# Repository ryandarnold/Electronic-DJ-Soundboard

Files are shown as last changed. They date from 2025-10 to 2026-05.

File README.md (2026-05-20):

# Electronic-DJ-Soundboard
The Electronic DJ Soundboard I designed in Eagle while serving as hardware lead on a 4-person team. I picked out the chips, designed the circuit, performed layout, soldered all components and tested and verified the board with a power supply and digital multimeter. 

I also coordinated with the embedded software lead on GPIO pin assignments, I/O functionality, communication protocol usage, and peripheral connections to support embedded firmware development.

<p align="center">
  
  <br>
  <em> The DJ circuit board outside its enclosure. I laser cut the enclosure and sanded it so it would fit together. </em>
</p>

<p align="center">
  
  <br>
  <em> The DJ circuit board from another angle. </em>
</p>

<p align="center">
  
  <br>
  <em> The main DJ circuit board.</em>
</p>

## Hardware: 

1. **TM4C123GH6PMI microcontroller launchpad** (as the main MCU for the project)
2. **Ceramic and Tantalum capacitors** (various purposes)
3. **ESP8266 Wifi module** (for saving user-made sound clips)
4. **TLV5618ACP DAC** (for outputting to the two speakers)
5. **MC34119 audio amplifier** (for amplifying the DAC output to the speakers)
6. **ULN2803a transistor array** (for powering the LED arrays)
7. **LM4041CILPR shunt voltage reference** (required for the TLV DAC)
8. **Resistors** (various purposes)
9. **Wire nuts** (for connecting the LEDs to the transistor array)
10. **LM2937 3.3 V regulator** (for powering different parts of the board)
11. **Testpoints** (for verifying that different parts of the board work)
12. **Blue, Red and Yellow LEDs** (to light the translucent buttons when pushed)
13. **MC7805ABTG 5V regulator** (for powering the LED array)
14. **8-ohm speakers** (for outputting user-made sounds)
15. **Audio jack** (so you can choose to use the built-in speakers or attach your own personal speaker for better sound quality)
16. **Pin headers**(to connect the launchpad to the board, and to have maximum flexibility in testing prototype)
17. **DC power connector** (to power the board)
18. **ST7735R LCD** (for displaying info to the user)
19. **Wood enclosure** (to store all electronics)
20. **Turn potentiometer** (for volume change)
21. **Slide potentiometer** (for tone change)

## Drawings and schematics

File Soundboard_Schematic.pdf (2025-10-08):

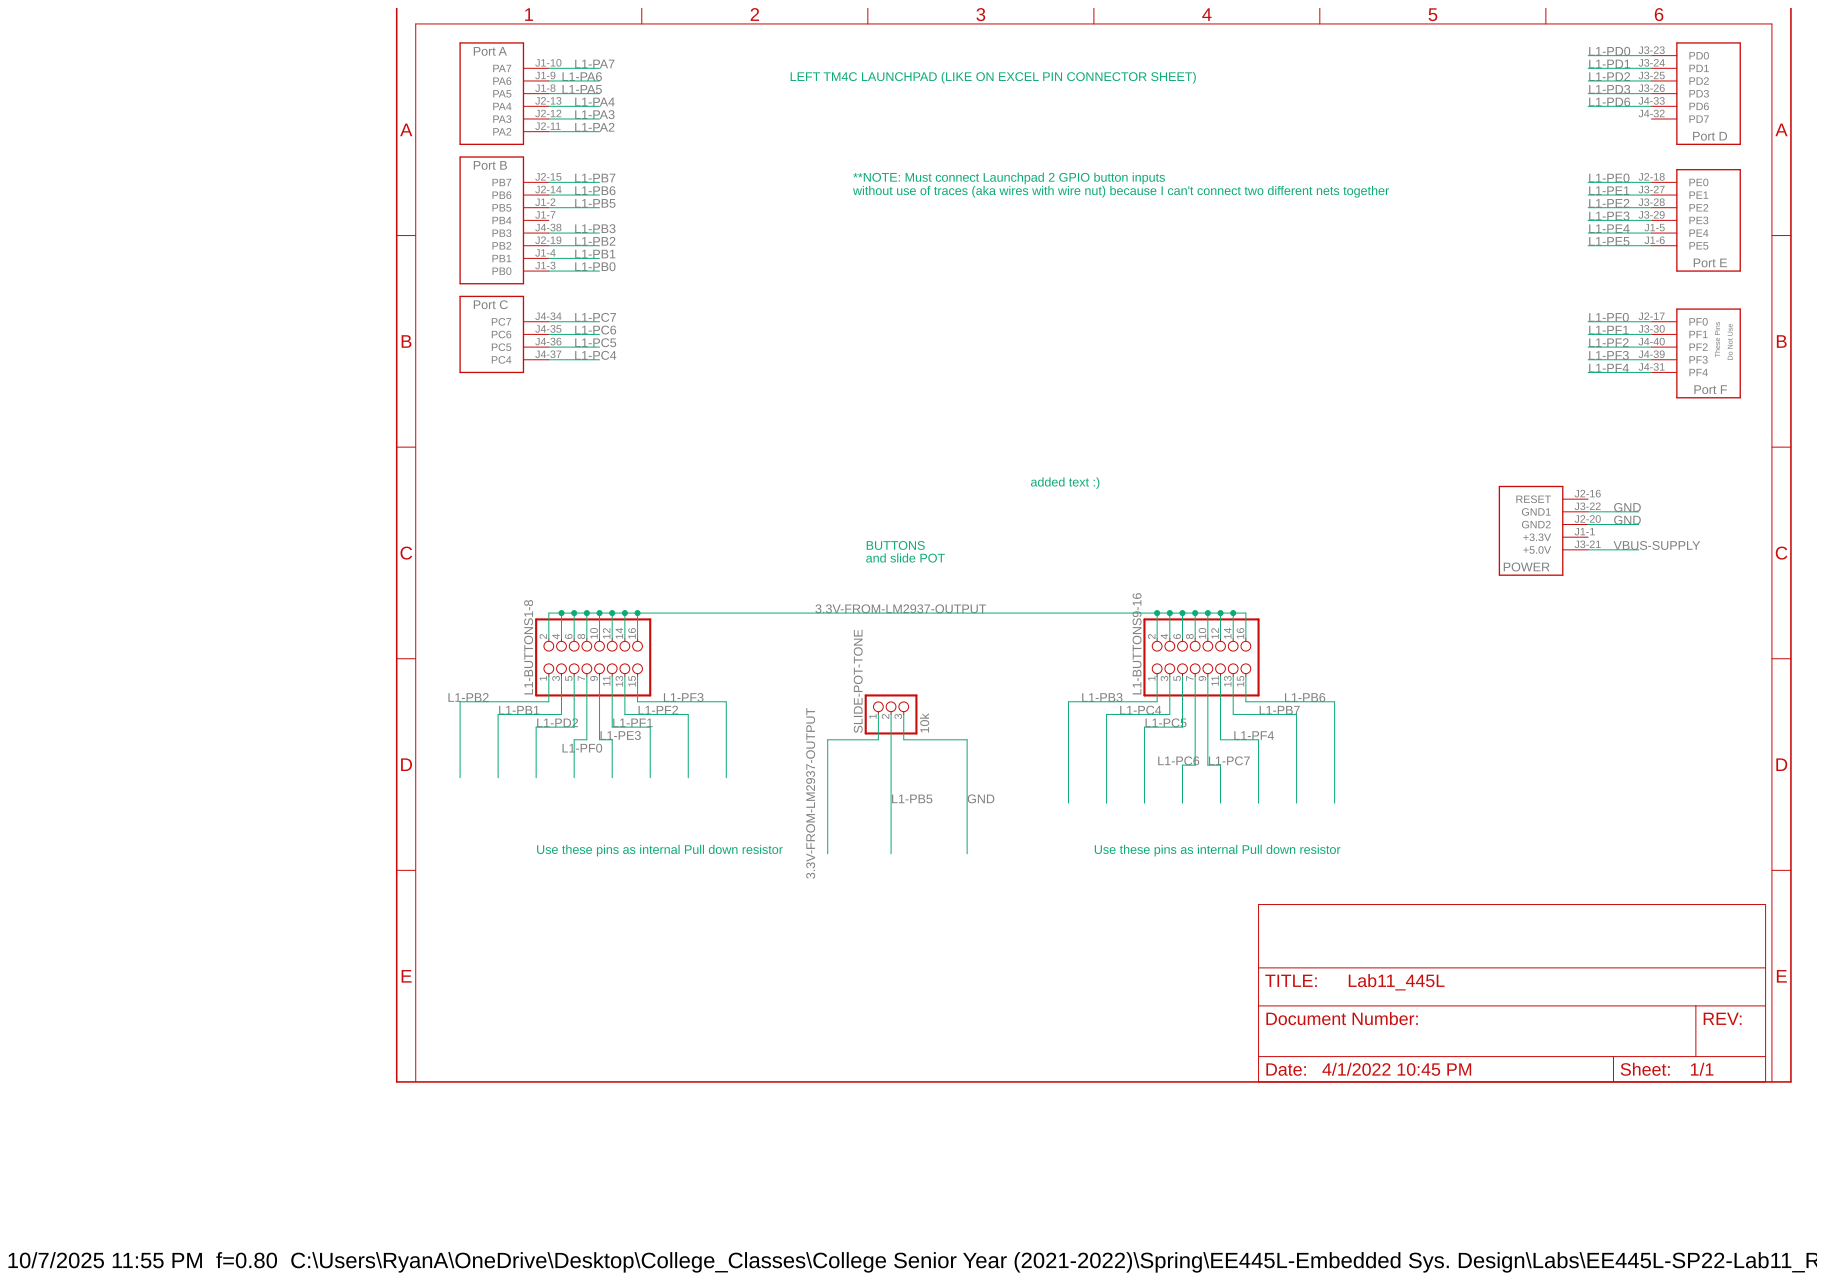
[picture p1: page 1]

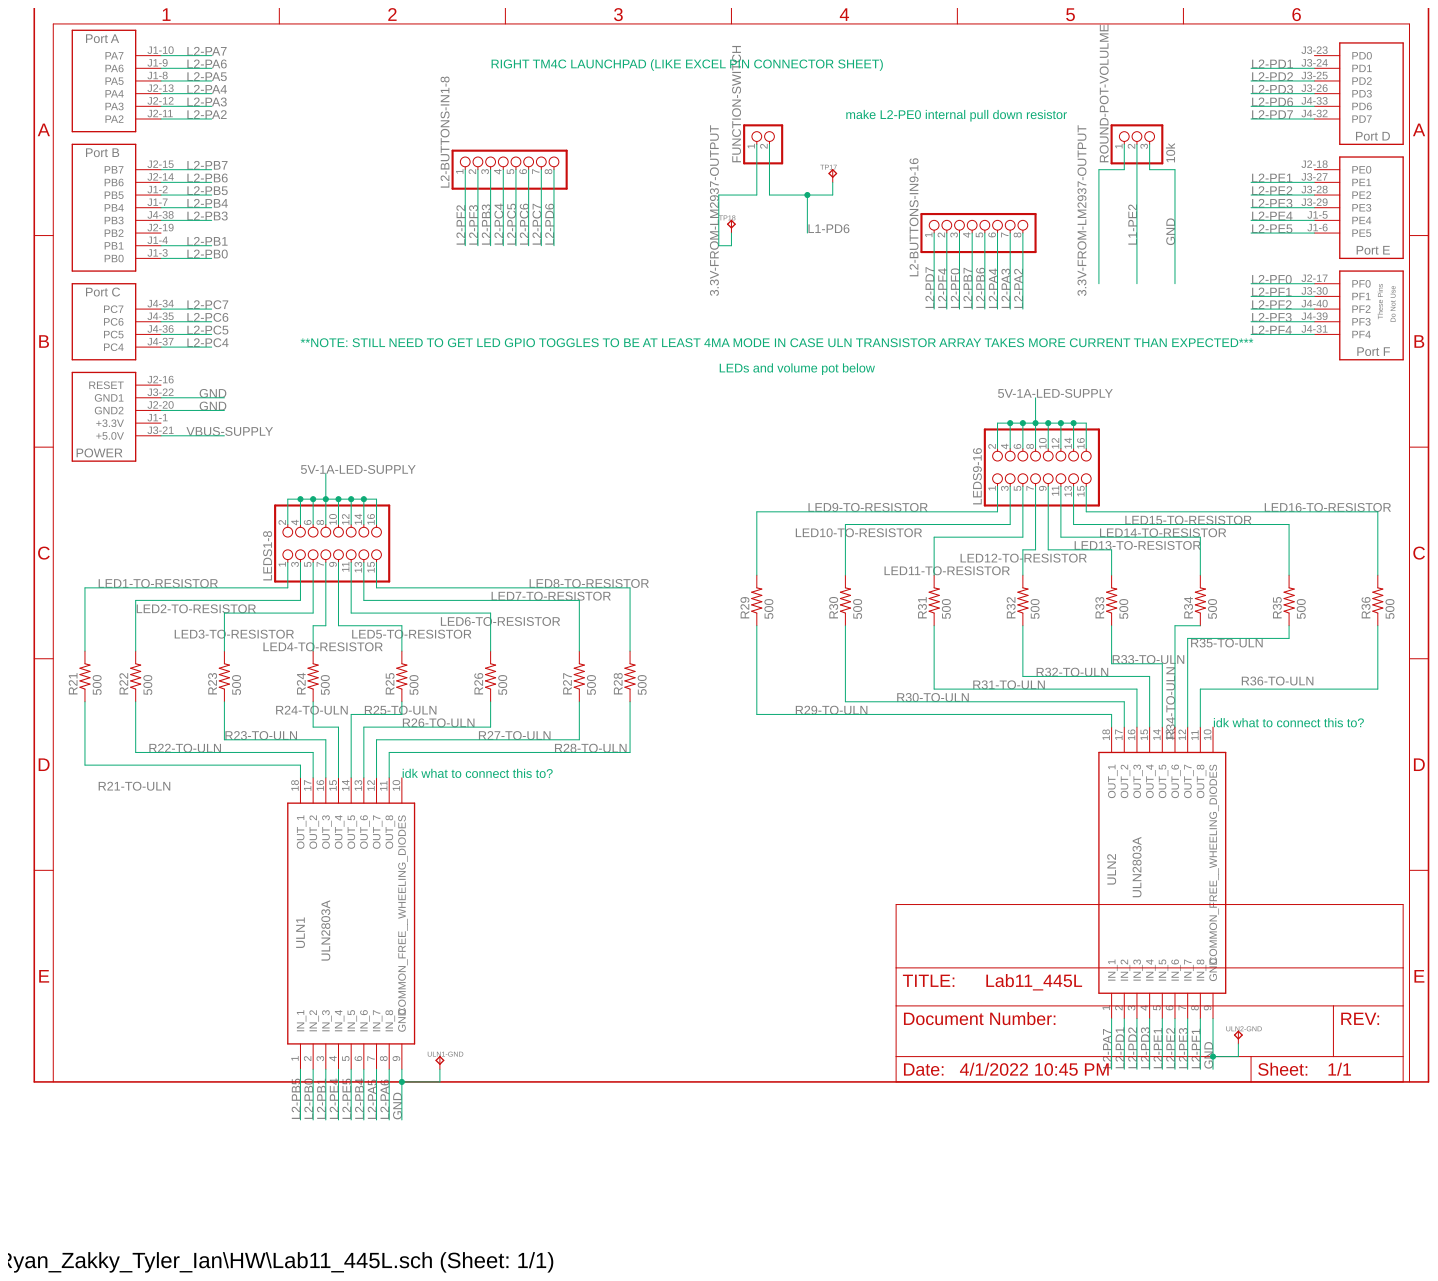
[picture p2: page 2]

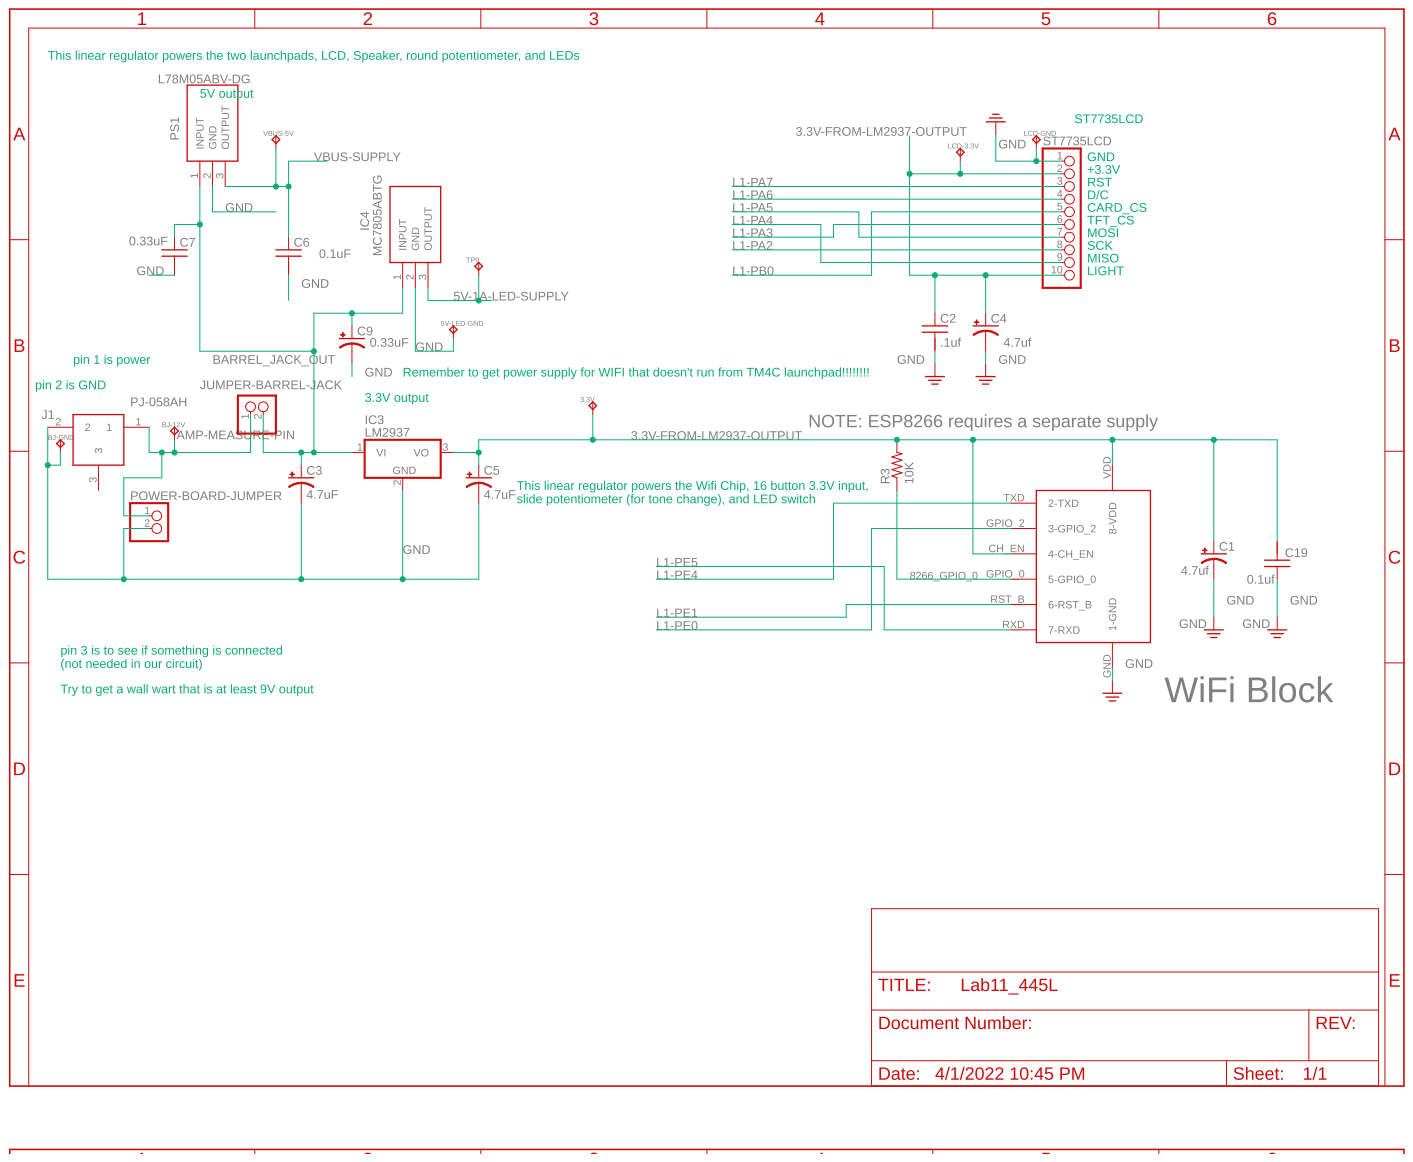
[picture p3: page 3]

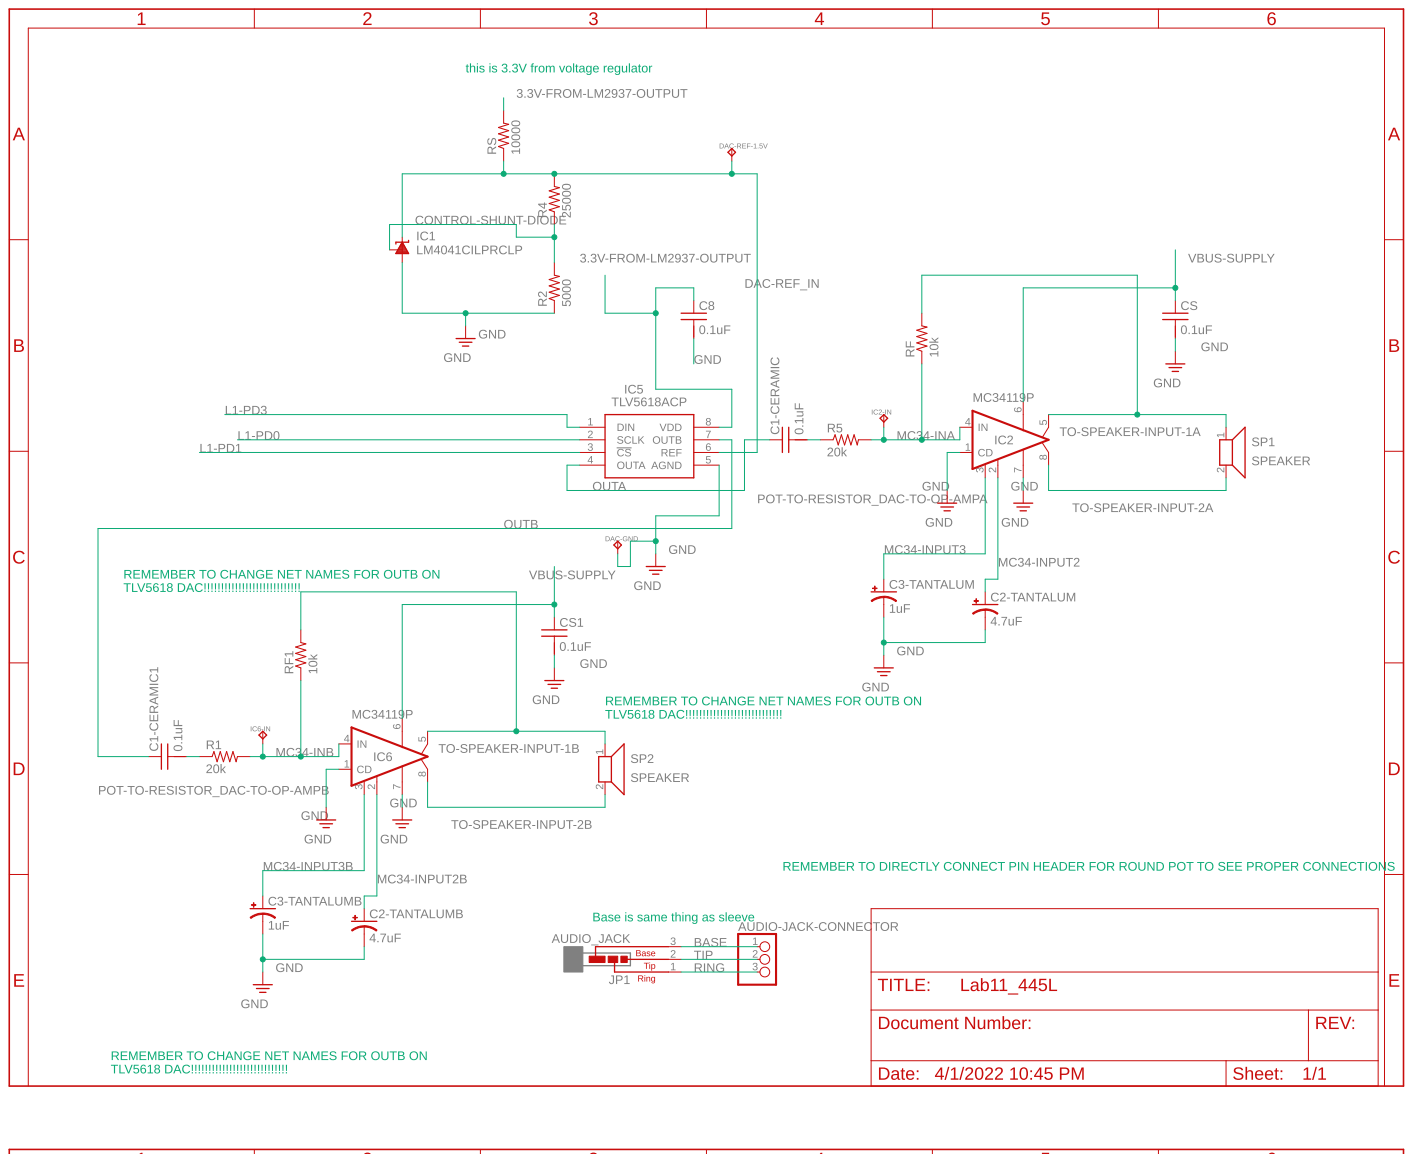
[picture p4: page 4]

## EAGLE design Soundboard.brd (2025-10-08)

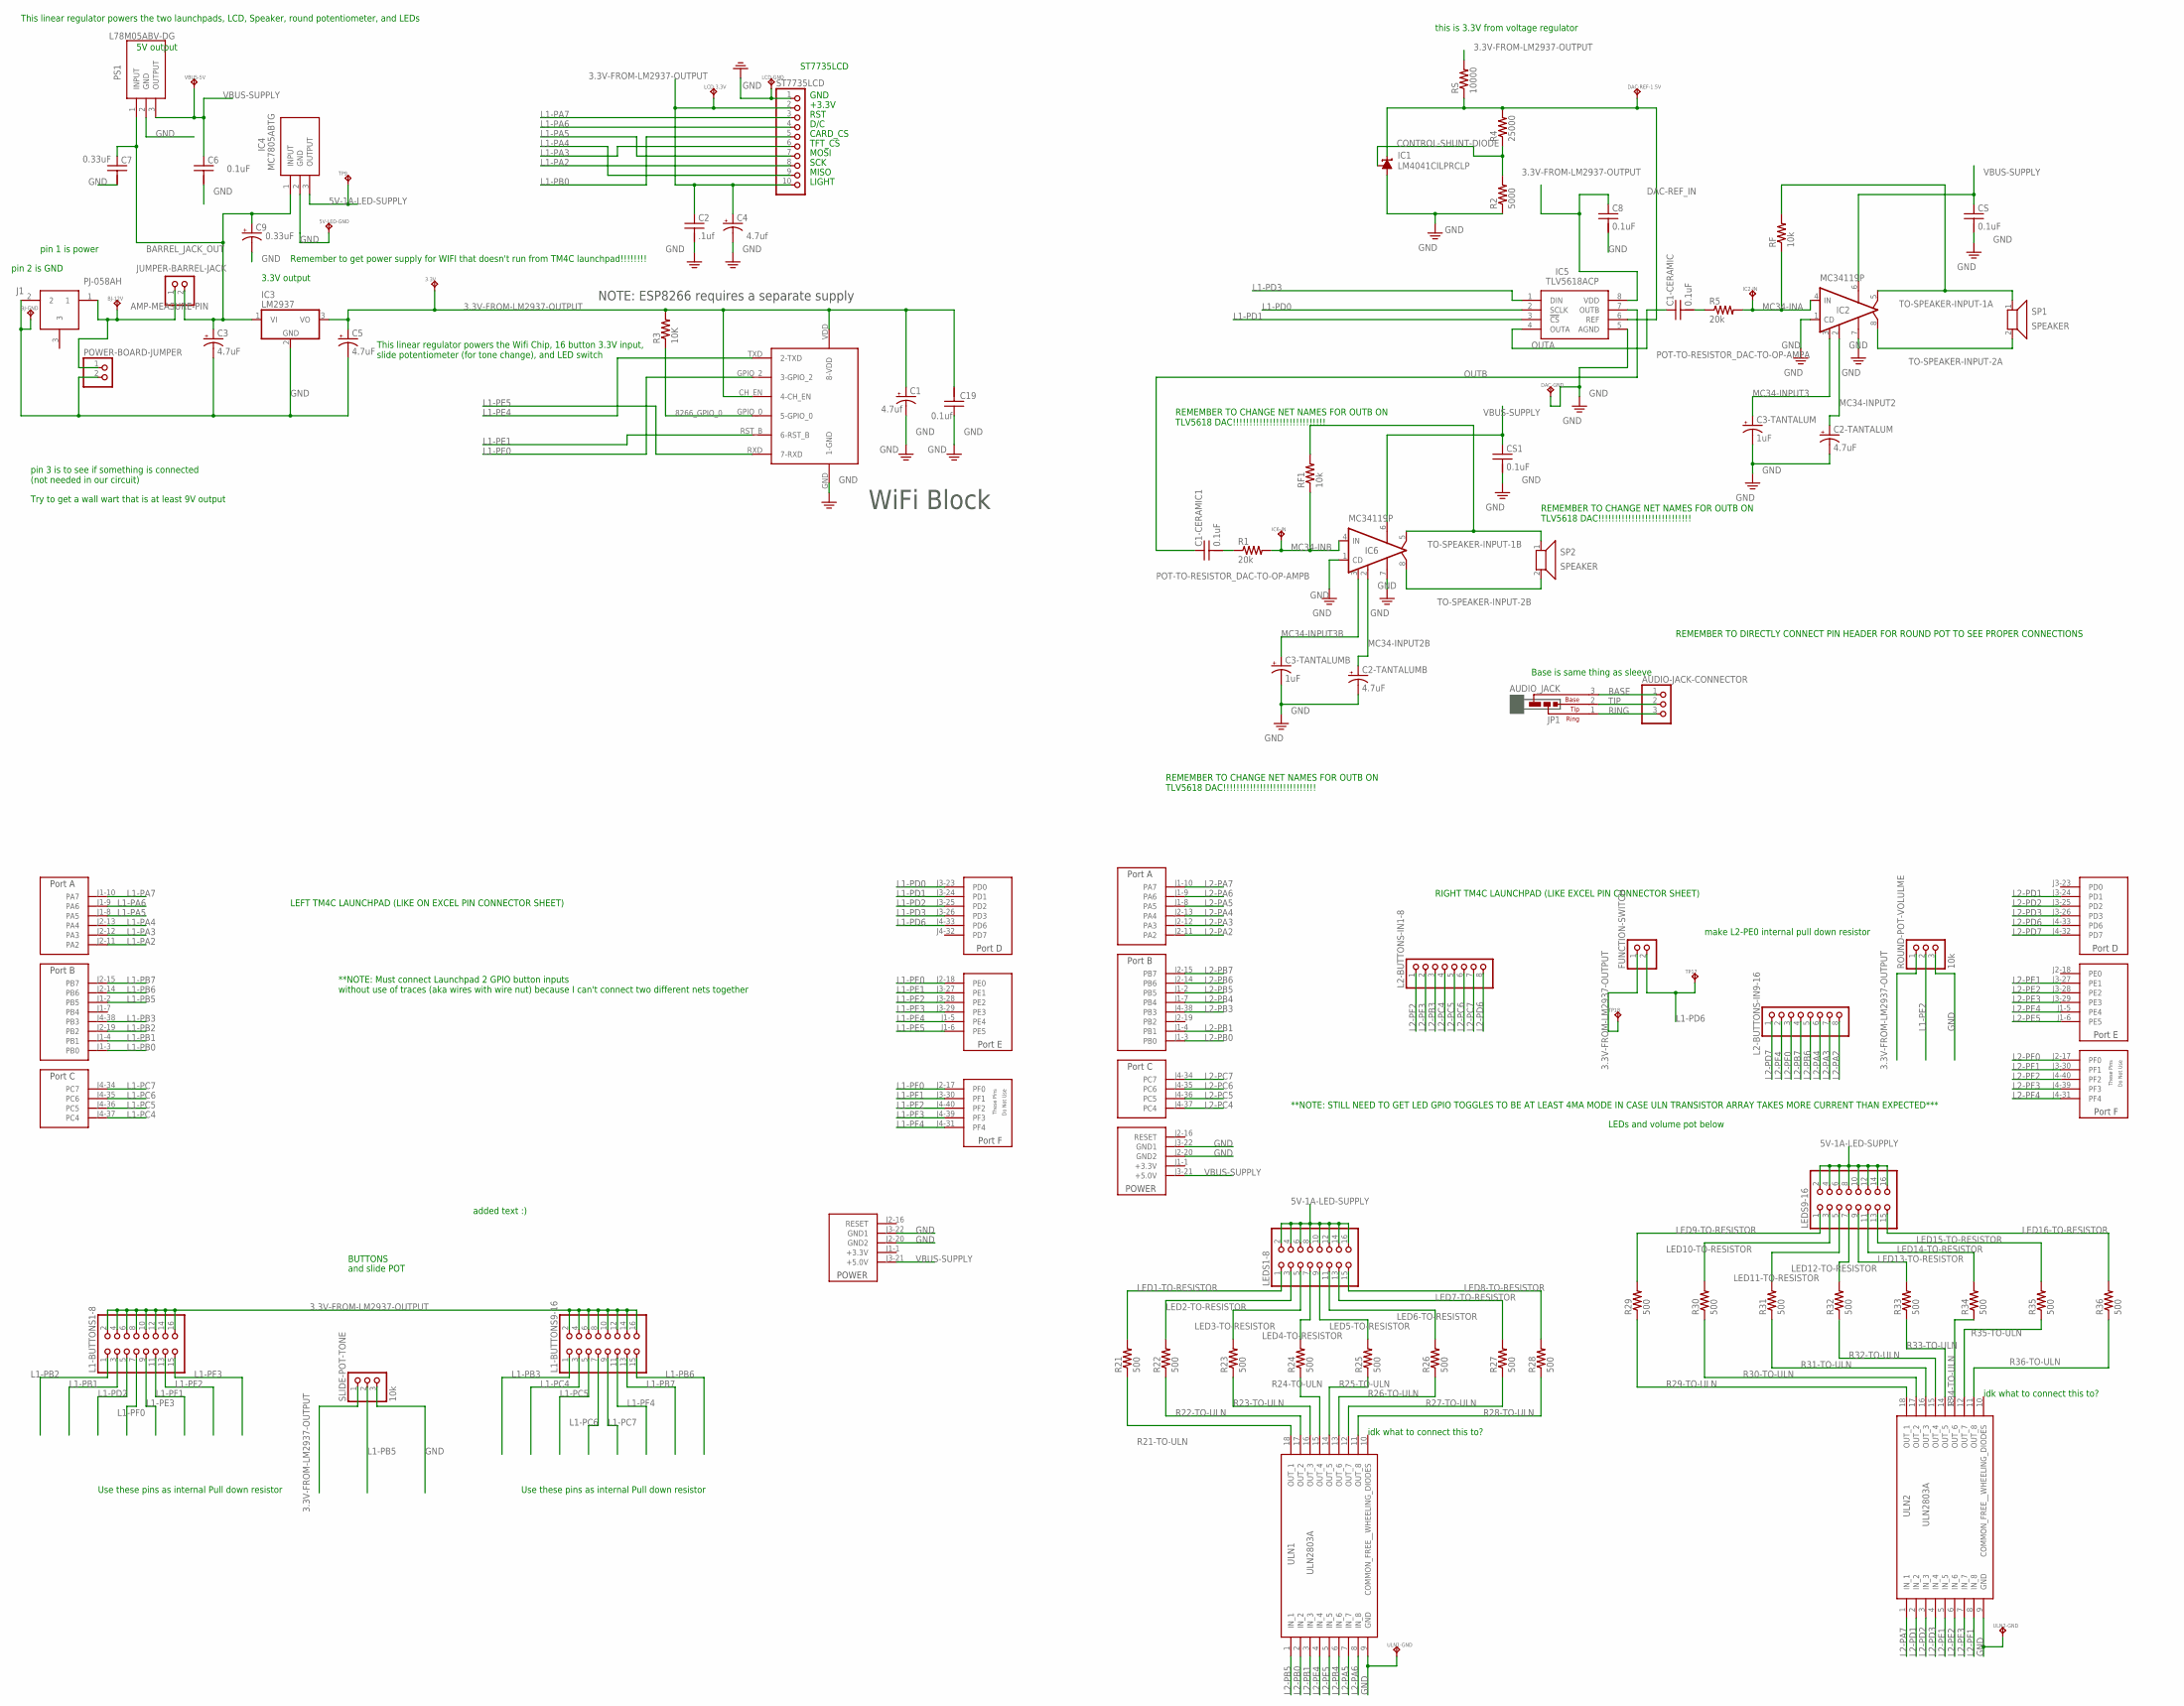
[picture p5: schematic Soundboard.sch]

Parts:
3.3V, 5V-LED-GND: TP_KEYSTONE500X; P1.1MM
AMP-MEASURE-PIN: PINHD-1X2; 1X02
AUDIO-JACK-CONNECTOR: PINHD-1X3; 1X03
BJ-12V: TP_KEYSTONE500X; P1.1MM
BJ-GND: TP_KEYSTONE500X; P1.1MM
C1, C4: 4.7uf; CAP200MILPOLARIZED
C1-CERAMIC, C1-CERAMIC1, C8: 0.1uF; CAP100MIL
C2: .1uf; CAP200MIL
C2-TANTALUM, C2-TANTALUMB, C3, C5: 4.7uF; CAP200MILPOLARIZED
C3-TANTALUM, C3-TANTALUMB: 1uF; CAP200MILPOLARIZED
C6: 0.1uF; CAP200MIL
C7: 0.33uF; CAP200MIL
C9: 0.33uF; CAP200MILPOLARIZED
C19: 0.1uf; CAP200MIL
CS, CS1: 0.1uF; CAP100MIL
DAC-GND: TP_KEYSTONE500X; P1.1MM
DAC-REF-1.5V: TP_KEYSTONE500X; P1.1MM
FUNCTION-SWITCH: PINHD-1X2; 1X02
IC1: LM4041CILPRCLP; LP_O-PBCY-W3
IC2, IC6: MC34119P; DIL08
IC2-IN, IC6-IN: TP_KEYSTONE500X; P1.1MM
IC3: LM2937; TO220
IC4: MC7805ABTG; TO254P482X997X2018-3P
IC5: TLV5618ACP; DIP794W53P254L959H508Q8N
J1: PJ-058AH; PJ058AH
JP1: AUDIO_JACK; JACK
L1-BUTTONS1-8, L1-BUTTONS9-16: PINHD-2X8; 2X08
L2-BUTTONS-IN1-8, L2-BUTTONS-IN9-16: PINHD-1X8; 1X08
LCD-3.3V: TP_KEYSTONE500X; P1.1MM
LCD-GND: TP_KEYSTONE500X; P1.1MM
LEDS1-8, LEDS9-16: PINHD-2X8; 2X08
POWER-BOARD-JUMPER: PINHD-1X2; 1X02
PS1: L78M05ABV-DG; TO255P460X1020X2008-3P
R1, R5: 20k; RES200MIL
R2: 5000; RES200MIL
R3: 10K; RES300MIL
R4: 25000; RES200MIL
R21, R22, R23, R24, R25, R26, R27, R28, R29, R30, R31, R32, R33, R34, R35, R36: 500; RES300MIL
RF, RF1: 10k; RES200MIL
ROUND-POT-VOLULME: 10k; 1X03
RS: 10000; RES200MIL
SLIDE-POT-TONE: 10k; 1X03
SP1, SP2: SPEAKER; 1X02
ST7735LCD: PINHD-1X10; 1X10
TP9, TP17, TP18: TP_KEYSTONE500X; P1.1MM
U$1: ESP_8266; ESP8266
U$2, U$3: TM4C_BP; TM4C_BOOSTER_PACK
ULN1, ULN2: ULN2803A; DIP850W46P254L2324H393Q18N
ULN1-GND, ULN2-GND: TP_KEYSTONE500X; P1.1MM
VBUS-5V: TP_KEYSTONE500X; P1.1MM

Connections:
3.3V-FROM-LM2937-OUTPUT: 3.3V.TP, C1.+, C2.1, C4.+, C5.+, C8.1, C19.2, FUNCTION-SWITCH.1, IC3.3 (VO), IC5.8 (VDD), L1-BUTTONS1-8.2, L1-BUTTONS1-8.4, L1-BUTTONS1-8.6, L1-BUTTONS1-8.8, L1-BUTTONS1-8.10, L1-BUTTONS1-8.12, L1-BUTTONS1-8.14, L1-BUTTONS1-8.16, L1-BUTTONS9-16.2, L1-BUTTONS9-16.4, L1-BUTTONS9-16.6, L1-BUTTONS9-16.8, L1-BUTTONS9-16.10, L1-BUTTONS9-16.12, L1-BUTTONS9-16.14, L1-BUTTONS9-16.16, LCD-3.3V.TP, R3.2, ROUND-POT-VOLULME.1, RS.2, SLIDE-POT-TONE.1, ST7735LCD.2, ST7735LCD.10, TP18.TP, U$1.CH_EN (4-CH_EN), U$1.VDD (8-VDD)
5V-1A-LED-SUPPLY: IC4.3 (OUTPUT), LEDS1-8.2, LEDS1-8.4, LEDS1-8.6, LEDS1-8.8, LEDS1-8.10, LEDS1-8.12, LEDS1-8.14, LEDS1-8.16, LEDS9-16.2, LEDS9-16.4, LEDS9-16.6, LEDS9-16.8, LEDS9-16.10, LEDS9-16.12, LEDS9-16.14, LEDS9-16.16, TP9.TP
8266_GPIO_0: R3.1, U$1.GPIO_0 (5-GPIO_0)
BARREL_JACK_OUT: AMP-MEASURE-PIN.1, BJ-12V.TP, J1.1, POWER-BOARD-JUMPER.1
BASE: AUDIO-JACK-CONNECTOR.1, JP1.3 (BASE)
CONTROL-SHUNT-DIODE: IC1.1 (FB), R2.2, R4.1
DAC-REF_IN: DAC-REF-1.5V.TP, IC1.2 (C), IC5.6 (REF), R4.2, RS.1
GND: 5V-LED-GND.TP, BJ-GND.TP, C1.-, C2.2, C2-TANTALUM.-, C2-TANTALUMB.-, C3.-, C3-TANTALUM.-, C3-TANTALUMB.-, C4.-, C5.-, C6.2, C7.2, C8.2, C9.-, C19.1, CS.2, CS1.2, DAC-GND.TP, IC1.3 (A), IC2.1 (CD), IC2.7 (GND), IC3.2 (GND), IC4.2 (GND), IC5.5 (AGND), IC6.1 (CD), IC6.7 (GND), J1.2, LCD-GND.TP, POWER-BOARD-JUMPER.2, PS1.2 (GND), R2.1, ROUND-POT-VOLULME.3, SLIDE-POT-TONE.3, ST7735LCD.1, U$1.GND (1-GND), U$2.J2-20 (GND2), U$2.J3-22 (GND1), U$3.J2-20 (GND2), U$3.J3-22 (GND1), ULN1.9 (GND), ULN1-GND.TP, ULN2.9 (GND), ULN2-GND.TP
JUMPER-BARREL-JACK: AMP-MEASURE-PIN.2, C3.+, C7.1, C9.+, IC3.1 (VI), IC4.1 (INPUT), PS1.1 (INPUT)
L1-PA2: ST7735LCD.8, U$2.J2-11 (PA2)
L1-PA3: ST7735LCD.6, U$2.J2-12 (PA3)
L1-PA4: ST7735LCD.9, U$2.J2-13 (PA4)
L1-PA5: ST7735LCD.7, U$2.J1-8 (PA5)
L1-PA6: ST7735LCD.4, U$2.J1-9 (PA6)
L1-PA7: ST7735LCD.3, U$2.J1-10 (PA7)
L1-PB0: ST7735LCD.5, U$2.J1-3 (PB0)
L1-PB1: L1-BUTTONS1-8.3, U$2.J1-4 (PB1)
L1-PB2: L1-BUTTONS1-8.1, U$2.J2-19 (PB2)
L1-PB3: L1-BUTTONS9-16.1, U$2.J4-38 (PB3)
L1-PB5: SLIDE-POT-TONE.2, U$2.J1-2 (PB5)
L1-PB6: L1-BUTTONS9-16.15, U$2.J2-14 (PB6)
L1-PB7: L1-BUTTONS9-16.13, U$2.J2-15 (PB7)
L1-PC4: L1-BUTTONS9-16.3, U$2.J4-37 (PC4)
L1-PC5: L1-BUTTONS9-16.5, U$2.J4-36 (PC5)
L1-PC6: L1-BUTTONS9-16.7, U$2.J4-35 (PC6)
L1-PC7: L1-BUTTONS9-16.9, U$2.J4-34 (PC7)
L1-PD0: IC5.2 (SCLK), U$2.J3-23 (PD0)
L1-PD1: IC5.3 (!CS), U$2.J3-24 (PD1)
L1-PD2: L1-BUTTONS1-8.5, U$2.J3-25 (PD2)
L1-PD3: IC5.1 (DIN), U$2.J3-26 (PD3)
L1-PD6: FUNCTION-SWITCH.2, TP17.TP, U$2.J4-33 (PD6)
L1-PE0: U$1.GPIO_2 (3-GPIO_2), U$2.J2-18 (PE0)
L1-PE1: U$1.RST_B (6-RST_B), U$2.J3-27 (PE1)
L1-PE2: ROUND-POT-VOLULME.2, U$2.J3-28 (PE2)
L1-PE3: L1-BUTTONS1-8.9, U$2.J3-29 (PE3)
L1-PE4: U$1.TXD (2-TXD), U$2.J1-5 (PE4)
L1-PE5: U$1.RXD (7-RXD), U$2.J1-6 (PE5)
L1-PF0: L1-BUTTONS1-8.7, U$2.J2-17 (PF0)
L1-PF1: L1-BUTTONS1-8.11, U$2.J3-30 (PF1)
L1-PF2: L1-BUTTONS1-8.13, U$2.J4-40 (PF2)
L1-PF3: L1-BUTTONS1-8.15, U$2.J4-39 (PF3)
L1-PF4: L1-BUTTONS9-16.11, U$2.J4-31 (PF4)
L2-PA2: L2-BUTTONS-IN9-16.8, U$3.J2-11 (PA2)
L2-PA3: L2-BUTTONS-IN9-16.7, U$3.J2-12 (PA3)
L2-PA4: L2-BUTTONS-IN9-16.6, U$3.J2-13 (PA4)
L2-PA5: U$3.J1-8 (PA5), ULN1.7 (IN_7)
L2-PA6: U$3.J1-9 (PA6), ULN1.8 (IN_8)
L2-PA7: U$3.J1-10 (PA7), ULN2.1 (IN_1)
L2-PB0: U$3.J1-3 (PB0), ULN1.2 (IN_2)
L2-PB1: U$3.J1-4 (PB1), ULN1.3 (IN_3)
L2-PB3: L2-BUTTONS-IN1-8.3, U$3.J4-38 (PB3)
L2-PB4: U$3.J1-7 (PB4), ULN1.6 (IN_6)
L2-PB5: U$3.J1-2 (PB5), ULN1.1 (IN_1)
L2-PB6: L2-BUTTONS-IN9-16.5, U$3.J2-14 (PB6)
L2-PB7: L2-BUTTONS-IN9-16.4, U$3.J2-15 (PB7)
L2-PC4: L2-BUTTONS-IN1-8.4, U$3.J4-37 (PC4)
L2-PC5: L2-BUTTONS-IN1-8.5, U$3.J4-36 (PC5)
L2-PC6: L2-BUTTONS-IN1-8.6, U$3.J4-35 (PC6)
L2-PC7: L2-BUTTONS-IN1-8.7, U$3.J4-34 (PC7)
L2-PD1: U$3.J3-24 (PD1), ULN2.2 (IN_2)
L2-PD2: U$3.J3-25 (PD2), ULN2.3 (IN_3)
L2-PD3: U$3.J3-26 (PD3), ULN2.4 (IN_4)
L2-PD6: L2-BUTTONS-IN1-8.8, U$3.J4-33 (PD6)
L2-PD7: L2-BUTTONS-IN9-16.1, U$3.J4-32 (PD7)
L2-PE1: U$3.J3-27 (PE1), ULN2.5 (IN_5)
L2-PE2: U$3.J3-28 (PE2), ULN2.6 (IN_6)
L2-PE3: U$3.J3-29 (PE3), ULN2.7 (IN_7)
L2-PE4: U$3.J1-5 (PE4), ULN1.4 (IN_4)
L2-PE5: U$3.J1-6 (PE5), ULN1.5 (IN_5)
L2-PF0: L2-BUTTONS-IN9-16.3, U$3.J2-17 (PF0)
L2-PF1: U$3.J3-30 (PF1), ULN2.8 (IN_8)
L2-PF2: L2-BUTTONS-IN1-8.1, U$3.J4-40 (PF2)
L2-PF3: L2-BUTTONS-IN1-8.2, U$3.J4-39 (PF3)
L2-PF4: L2-BUTTONS-IN9-16.2, U$3.J4-31 (PF4)
LED1-TO-RESISTOR: LEDS1-8.1, R21.2
LED2-TO-RESISTOR: LEDS1-8.3, R22.2
LED3-TO-RESISTOR: LEDS1-8.5, R23.2
LED4-TO-RESISTOR: LEDS1-8.7, R24.2
LED5-TO-RESISTOR: LEDS1-8.9, R25.2
LED6-TO-RESISTOR: LEDS1-8.11, R26.2
LED7-TO-RESISTOR: LEDS1-8.13, R27.2
LED8-TO-RESISTOR: LEDS1-8.15, R28.2
LED9-TO-RESISTOR: LEDS9-16.1, R29.2
LED10-TO-RESISTOR: LEDS9-16.3, R30.2
LED11-TO-RESISTOR: LEDS9-16.5, R31.2
LED12-TO-RESISTOR: LEDS9-16.7, R32.2
LED13-TO-RESISTOR: LEDS9-16.9, R33.2
LED14-TO-RESISTOR: LEDS9-16.11, R34.2
LED15-TO-RESISTOR: LEDS9-16.13, R35.2
LED16-TO-RESISTOR: LEDS9-16.15, R36.2
MC34-INA: IC2.4 (IN), IC2-IN.TP, R5.2, RF.1
MC34-INB: IC6.4 (IN), IC6-IN.TP, R1.2, RF1.1
MC34-INPUT2: C2-TANTALUM.+, IC2.2 (FC2)
MC34-INPUT2B: C2-TANTALUMB.+, IC6.2 (FC2)
MC34-INPUT3: C3-TANTALUM.+, IC2.3 (FC1)
MC34-INPUT3B: C3-TANTALUMB.+, IC6.3 (FC1)
OUTA: C1-CERAMIC.1, IC5.4 (OUTA)
OUTB: C1-CERAMIC1.1, IC5.7 (OUTB)
POT-TO-RESISTOR_DAC-TO-OP-AMPA: C1-CERAMIC.2, R5.1
POT-TO-RESISTOR_DAC-TO-OP-AMPB: C1-CERAMIC1.2, R1.1
R21-TO-ULN: R21.1, ULN1.18 (OUT_1)
R22-TO-ULN: R22.1, ULN1.17 (OUT_2)
R23-TO-ULN: R23.1, ULN1.16 (OUT_3)
R24-TO-ULN: R24.1, ULN1.15 (OUT_4)
R25-TO-ULN: R25.1, ULN1.14 (OUT_5)
R26-TO-ULN: R26.1, ULN1.13 (OUT_6)
R27-TO-ULN: R27.1, ULN1.12 (OUT_7)
R28-TO-ULN: R28.1, ULN1.11 (OUT_8)
R29-TO-ULN: R29.1, ULN2.18 (OUT_1)
R30-TO-ULN: R30.1, ULN2.17 (OUT_2)
R31-TO-ULN: R31.1, ULN2.16 (OUT_3)
R32-TO-ULN: R32.1, ULN2.15 (OUT_4)
R33-TO-ULN: R33.1, ULN2.14 (OUT_5)
R34-TO-ULN: R34.1, ULN2.13 (OUT_6)
R35-TO-ULN: R35.1, ULN2.12 (OUT_7)
R36-TO-ULN: R36.1, ULN2.11 (OUT_8)
RING: AUDIO-JACK-CONNECTOR.3, JP1.1 (RING)
TIP: AUDIO-JACK-CONNECTOR.2, JP1.2 (TIP)
TO-SPEAKER-INPUT-1A: IC2.5 (VO1), RF.2, SP1.1
TO-SPEAKER-INPUT-1B: IC6.5 (VO1), RF1.2, SP2.1
TO-SPEAKER-INPUT-2A: IC2.8 (VO2), SP1.2
TO-SPEAKER-INPUT-2B: IC6.8 (VO2), SP2.2
VBUS-SUPPLY: C6.1, CS.1, CS1.1, IC2.6 (VCC), IC6.6 (VCC), PS1.3 (OUTPUT), U$2.J3-21 (+5.0V), U$3.J3-21 (+5.0V), VBUS-5V.TP

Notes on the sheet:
WiFi Block
NOTE: ESP8266 requires a separate supply
Remember to get power supply for WIFI that doesn't run from TM4C launchpad!!!!!!!!
LEFT TM4C LAUNCHPAD (LIKE ON EXCEL PIN CONNECTOR SHEET)
RIGHT TM4C LAUNCHPAD (LIKE EXCEL PIN CONNECTOR SHEET)
Try to get a wall wart that is at least 9V output
5V output
3.3V output
This linear regulator powers the two launchpads, LCD, Speaker, round potentiometer, and LEDs
This linear regulator powers the Wifi Chip, 16 button 3.3V input, slide potentiometer (for tone change), and LED switch
BUTTONS
**NOTE: Must connect Launchpad 2 GPIO button inputs without use of traces (aka wires with wire nut) because I can't connect two different nets together
LEDs and volume pot below
and slide POT
pin 1 is power
pin 2 is GND
pin 3 is to see if something is connected (not needed in our circuit)
GND
+3.3V
RST
D/C
CARD_CS
TFT_CS
MOSI
SCK
MISO
LIGHT
ST7735LCD
REMEMBER TO DIRECTLY CONNECT PIN HEADER FOR ROUND POT TO SEE PROPER CONNECTIONS
Use these pins as internal Pull down resistor
REMEMBER TO CHANGE NET NAMES FOR OUTB ON TLV5618 DAC!!!!!!!!!!!!!!!!!!!!!!!!!!!!
this is 3.3V from voltage regulator
make L2-PE0 internal pull down resistor
Base is same thing as sleeve
**NOTE: STILL NEED TO GET LED GPIO TOGGLES TO BE AT LEAST 4MA MODE IN CASE ULN TRANSISTOR ARRAY TAKES MORE CURRENT THAN EXPECTED***
added text :)
idk what to connect this to?

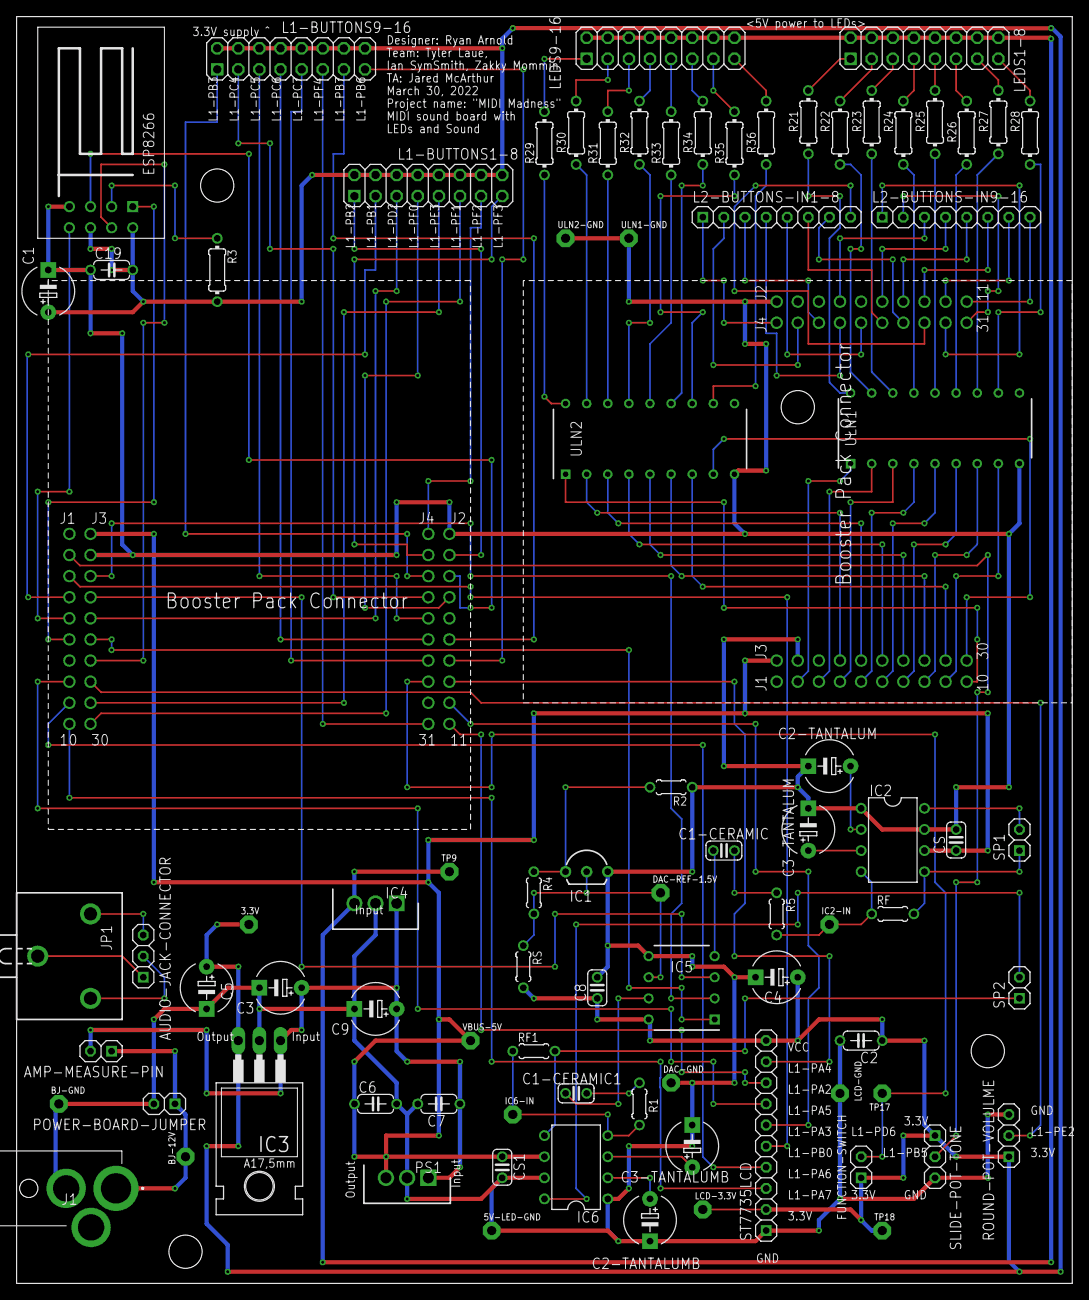
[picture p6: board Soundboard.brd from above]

Board: 2 copper layers, 127.0 x 152.4 mm, 87 parts (0 on the bottom side), 123 nets.

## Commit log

2025-10-08 Uploaded the main .sch and .brd files
    [Lab11_445L.brd, Lab11_445L.sch]
2025-10-08 Changed name to Soundboard
    [Soundboard.brd]
2025-10-08 Added the Soundboard Schematic
